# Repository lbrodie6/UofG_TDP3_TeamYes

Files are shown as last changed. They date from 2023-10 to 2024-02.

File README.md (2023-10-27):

# UofG_TDP3_TeamYes
UofG TDP3 repo for KiCAD files and code
# File Structure
- hardware: KiCad files. All PCBs can be done within the Main_Project file
    - mechanical: Mechanical CAD files. Fusion 360 .f3d, STLs and Gcode files for 3D printing are all stored here
    - photomasks: Photomasks for PCB fabrication output
- lib: Footprint libraries. Contains any custom footprints used (such as for the FRDM board).
- software: Contains C++ code

## Reference
- TCS34725 Color Sensor design files: https://github.com/adafruit/Adafruit-Flora-TCS34725-Color-Sensor-PCB/tree/master -- could be used for footprint reference
- TCS3472 mbed software library: https://os.mbed.com/users/Allar/code/TCS3472_I2C/docs/tip/classTCS3472__I2C.html
- TCS34725 datasheet: https://cdn-shop.adafruit.com/datasheets/TCS34725.pdf

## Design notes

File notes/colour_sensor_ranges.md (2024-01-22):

# Colour Sensor Ranges
C = Clear
R = Red
G = Green
B = Blue
  
### No Standoffs:
  - Red Disc: 1091C, 515R, 292G, 305B
  - Blue Disc: 992C, 243R, 328G, 419B
  - On Line: 830C, 244R, 277G, 278B
  - Off Line: 1599C, 502R, 531G, 525B

### With 6mm Standoffs:
  - Red Disc: 1140C, 557R, 270G, 284B
  - Blue Disc: 1015C, 213R, 313G, 432B
  - On Line: 712C, 199R, 228G, 234B
  - Off Line: 1781C, 540R, 578G, 575B

Tested on 19/01/24 by Izaak

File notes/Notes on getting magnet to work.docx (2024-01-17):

Setting to 12V – results in 500mA for magnet

- Logic LOW is when magnet is on – due to switch being open (should remember for programming)
- Should get a heatsink for MOSFET because it gets hawt

First:

Used just a MOSFET, and couldn’t get it working – because no pull down resistor so floating pin

- Needed at least a pull up resistor or current limiting resistor for MOSFET

Then:

Added flyback diode (1N4007) as a schottkey flyback to protect from emf spikes

Added a bjt transistor to step up 3.3V logic level from MCU to 5V – 3.3V wasn’t enough to turn on the MOSFET.

Tried different voltages to drive MOSFETs.

Higher MOSFET driving votlage means a strong magnet pull but pulls more current

MOSFET voltage | Current draw
12V | 530mA
9V | 420mA
7V | 330mA
5V | 250mA
<5V | Weak pull on magnet

Could use a voltage divider to control the current drawn – can adjust and swap these resistor values if we want to change current drawn.

- Solenoid is meant to work properly at 12V – so shall keep

http://tinyurl.com/yudysefc --- for magnet driver circuit

FET: IRF620

BJT: BC547

Diode: Schottkey (1N4007)

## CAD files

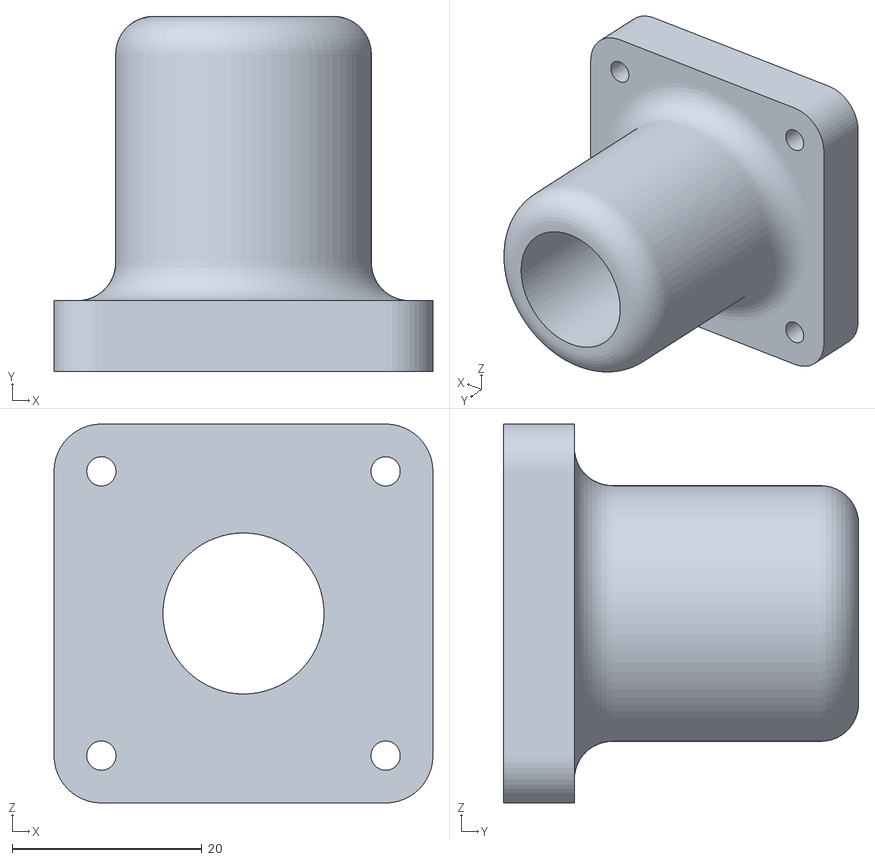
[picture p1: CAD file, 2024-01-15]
hardware/mechanical/TDP3SensorOccluder v0.stl
40.0 x 37.5 x 40.0

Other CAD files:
hardware/mechanical/GoggleOccluder.f3d
hardware/mechanical/TDP3SensorOccluder.f3d

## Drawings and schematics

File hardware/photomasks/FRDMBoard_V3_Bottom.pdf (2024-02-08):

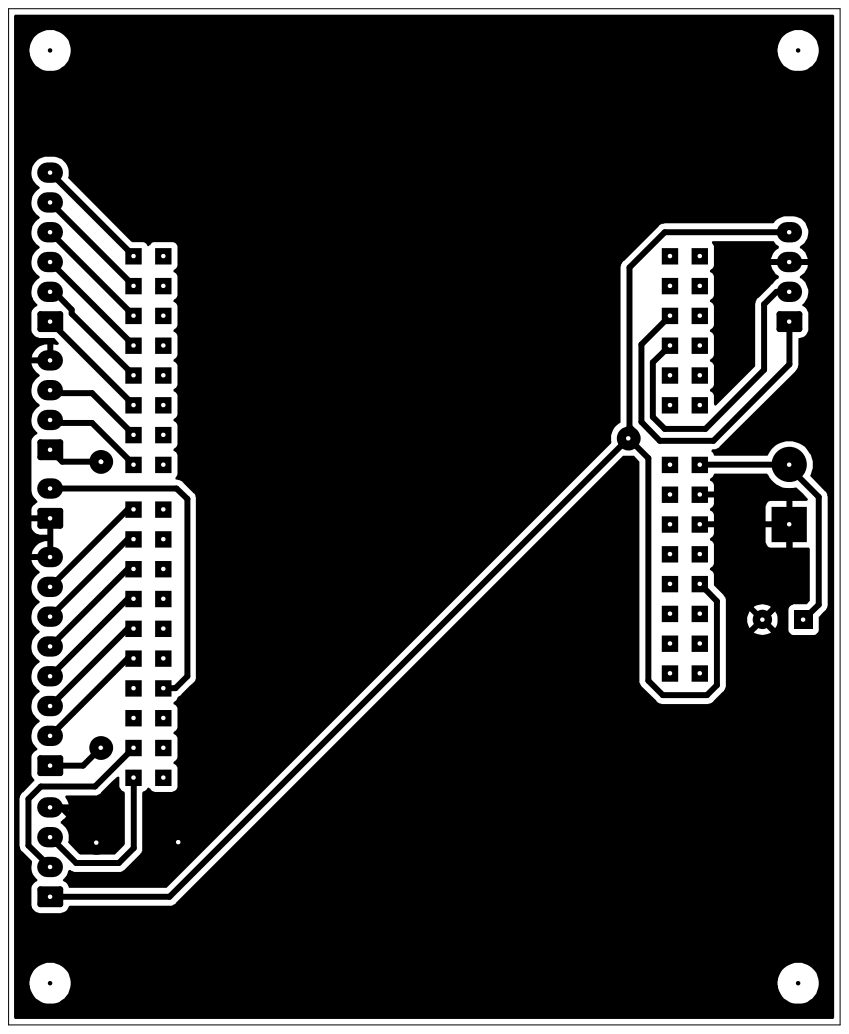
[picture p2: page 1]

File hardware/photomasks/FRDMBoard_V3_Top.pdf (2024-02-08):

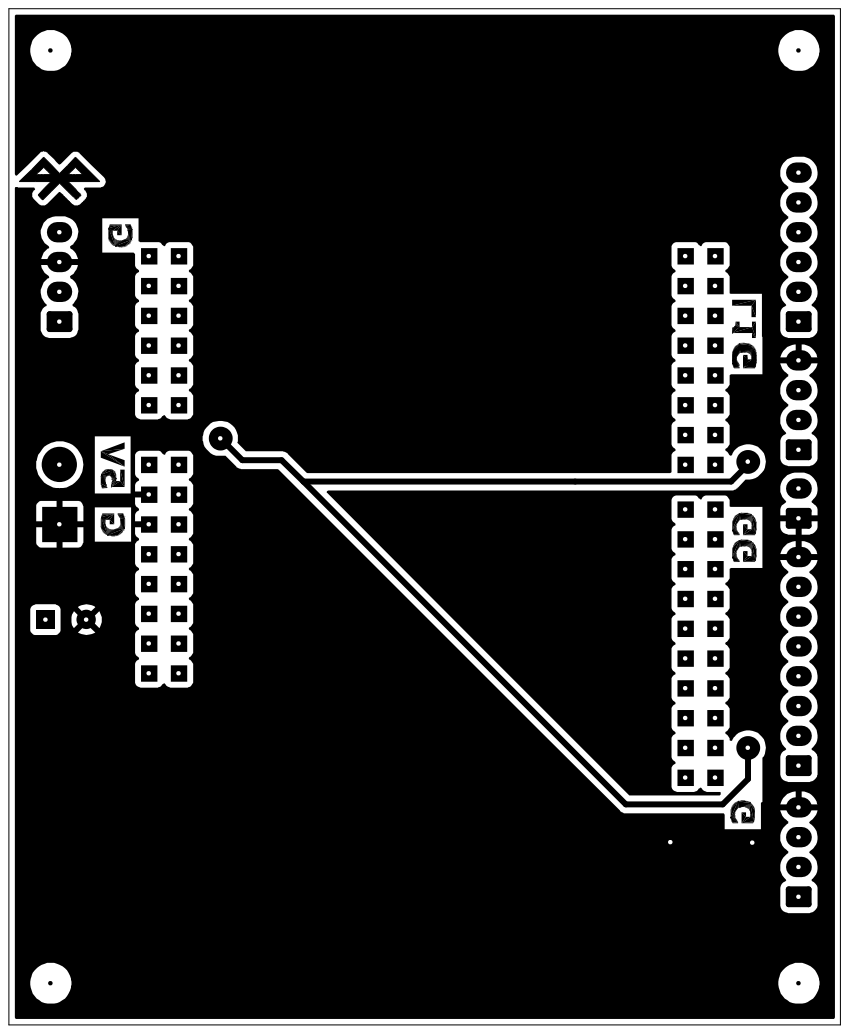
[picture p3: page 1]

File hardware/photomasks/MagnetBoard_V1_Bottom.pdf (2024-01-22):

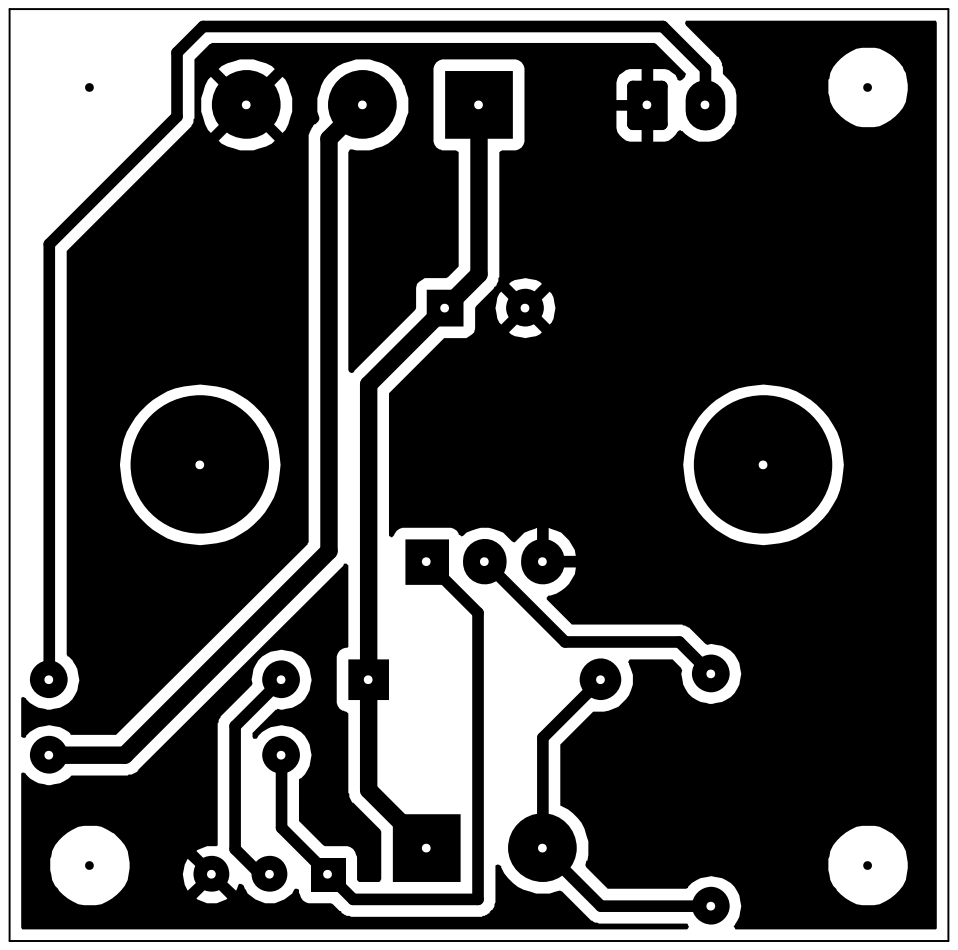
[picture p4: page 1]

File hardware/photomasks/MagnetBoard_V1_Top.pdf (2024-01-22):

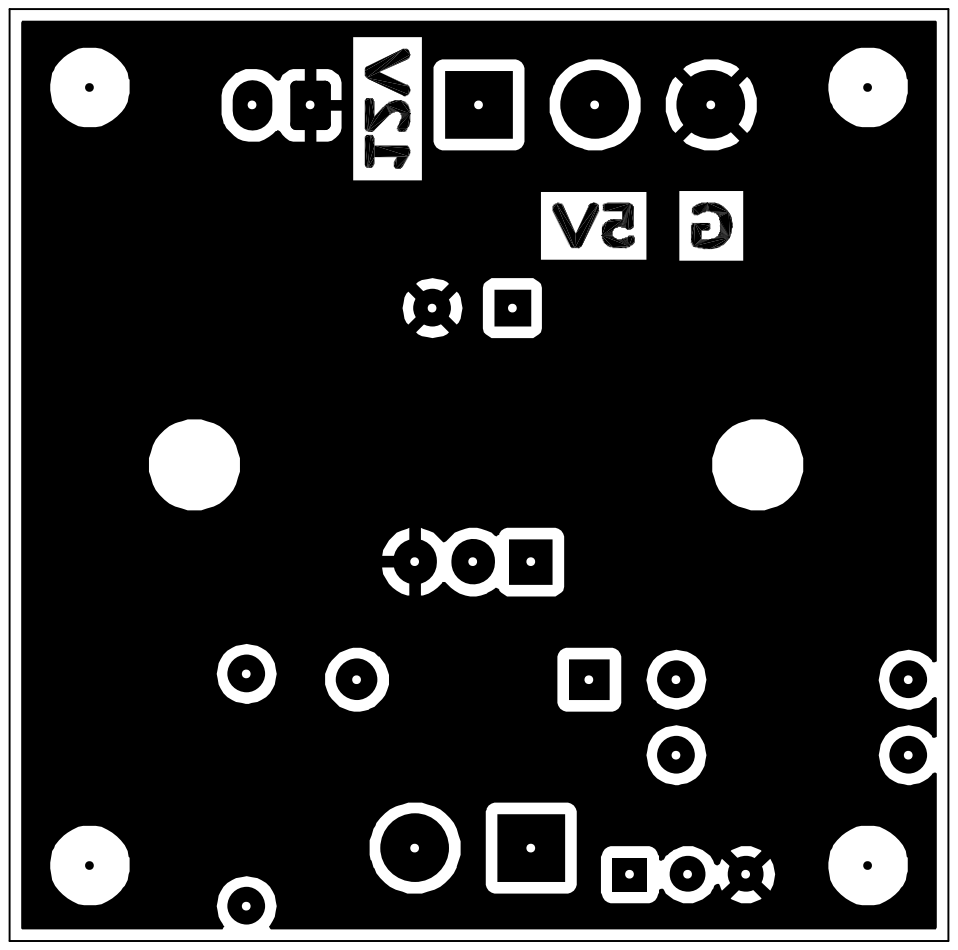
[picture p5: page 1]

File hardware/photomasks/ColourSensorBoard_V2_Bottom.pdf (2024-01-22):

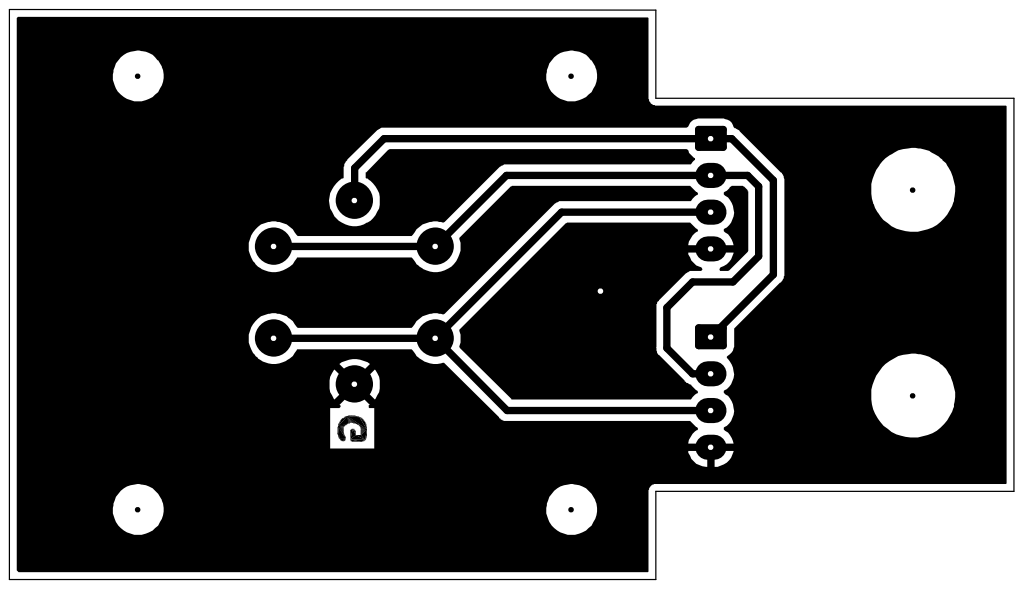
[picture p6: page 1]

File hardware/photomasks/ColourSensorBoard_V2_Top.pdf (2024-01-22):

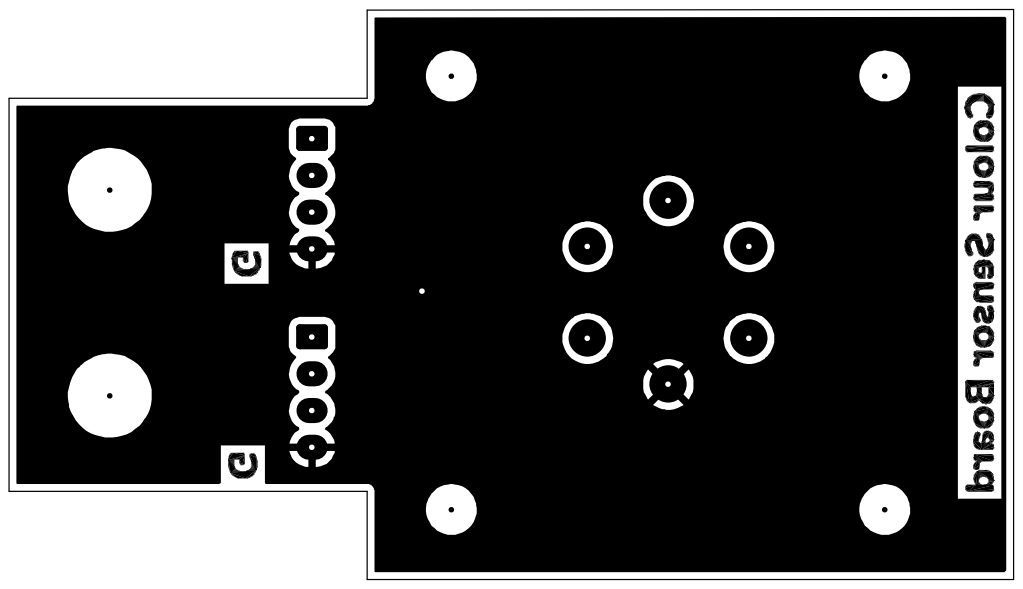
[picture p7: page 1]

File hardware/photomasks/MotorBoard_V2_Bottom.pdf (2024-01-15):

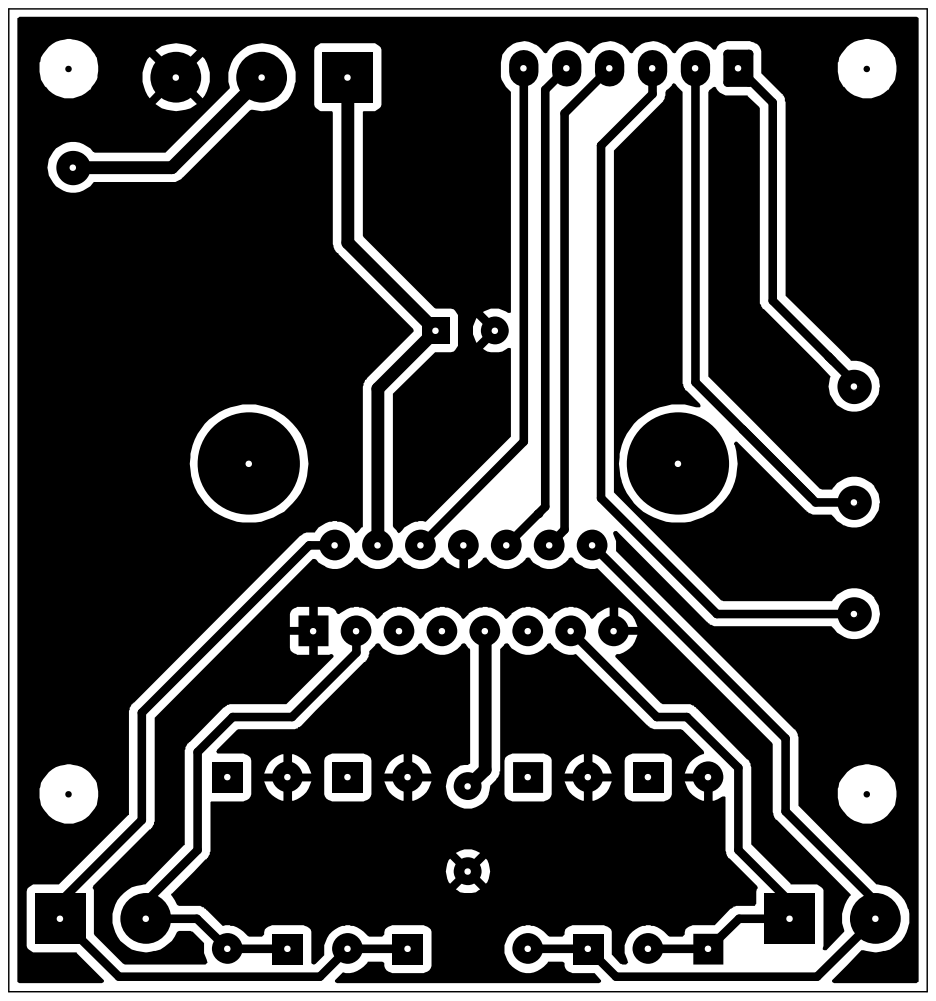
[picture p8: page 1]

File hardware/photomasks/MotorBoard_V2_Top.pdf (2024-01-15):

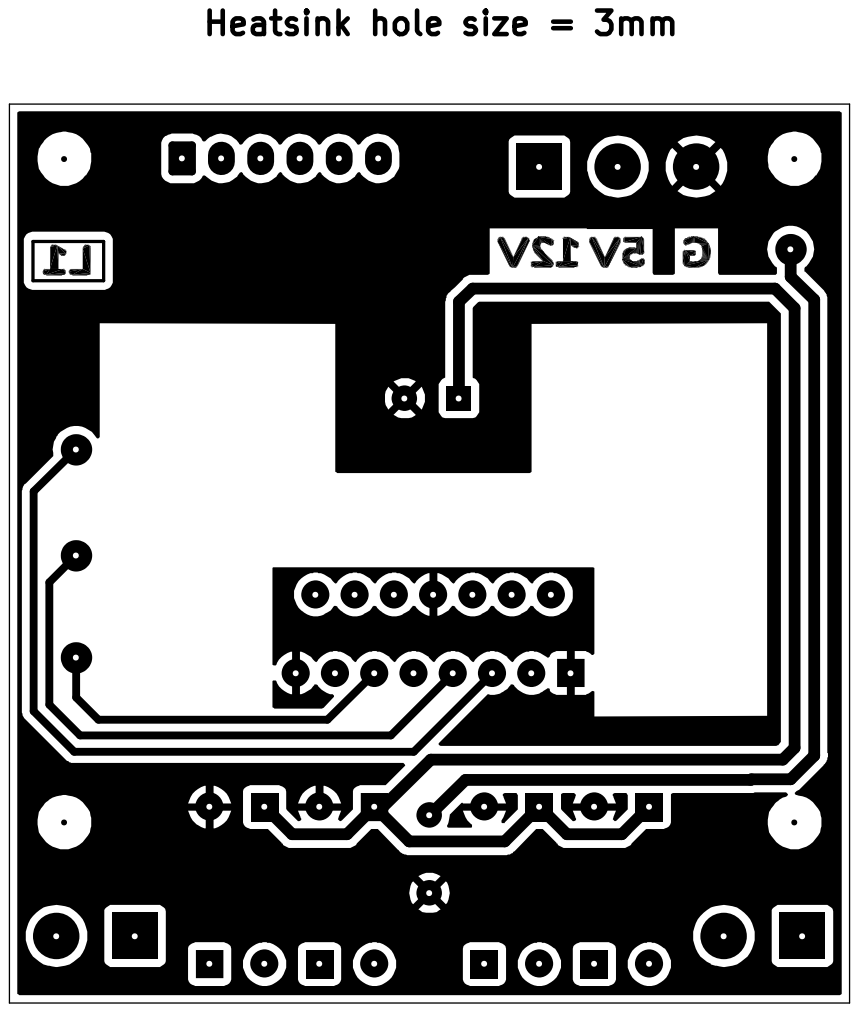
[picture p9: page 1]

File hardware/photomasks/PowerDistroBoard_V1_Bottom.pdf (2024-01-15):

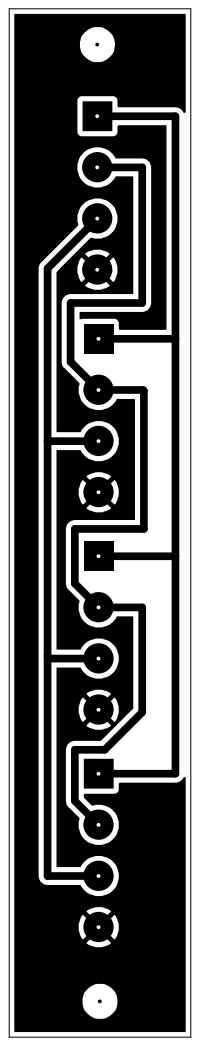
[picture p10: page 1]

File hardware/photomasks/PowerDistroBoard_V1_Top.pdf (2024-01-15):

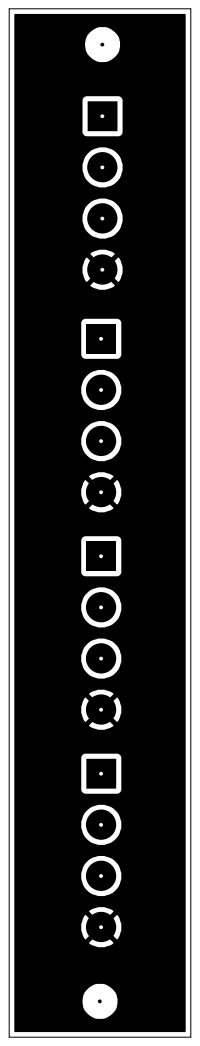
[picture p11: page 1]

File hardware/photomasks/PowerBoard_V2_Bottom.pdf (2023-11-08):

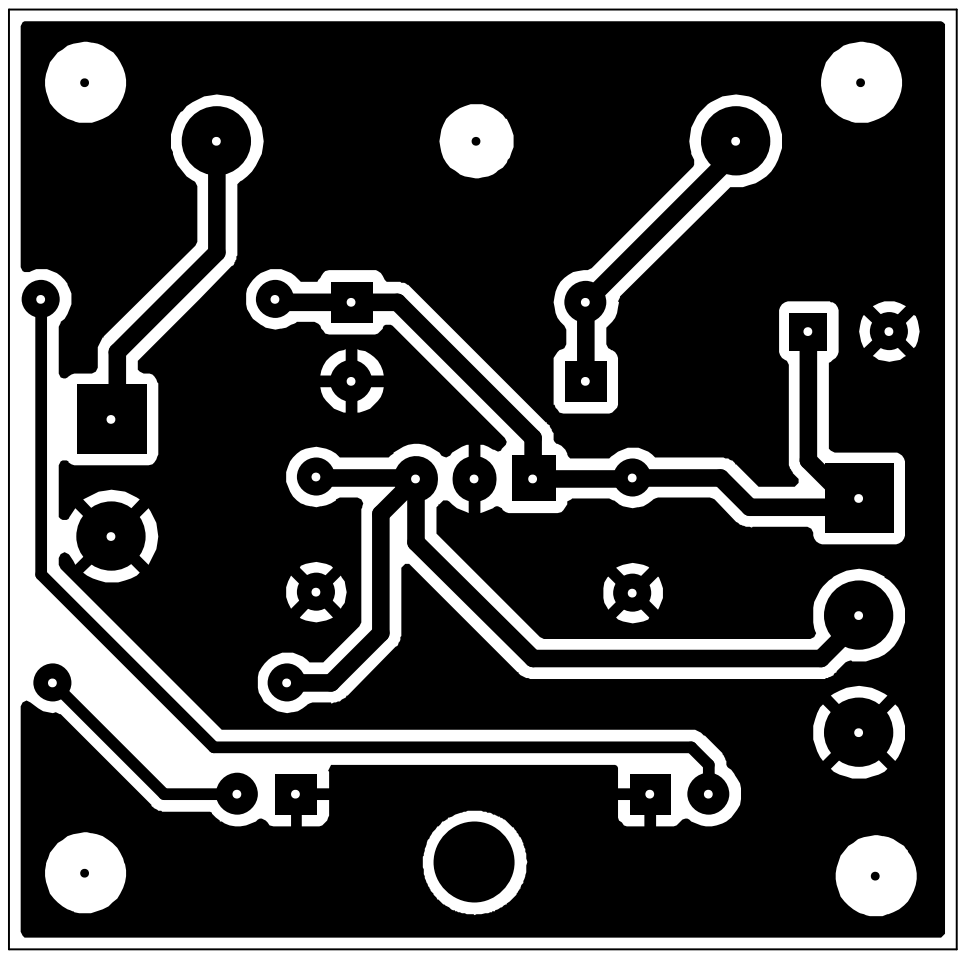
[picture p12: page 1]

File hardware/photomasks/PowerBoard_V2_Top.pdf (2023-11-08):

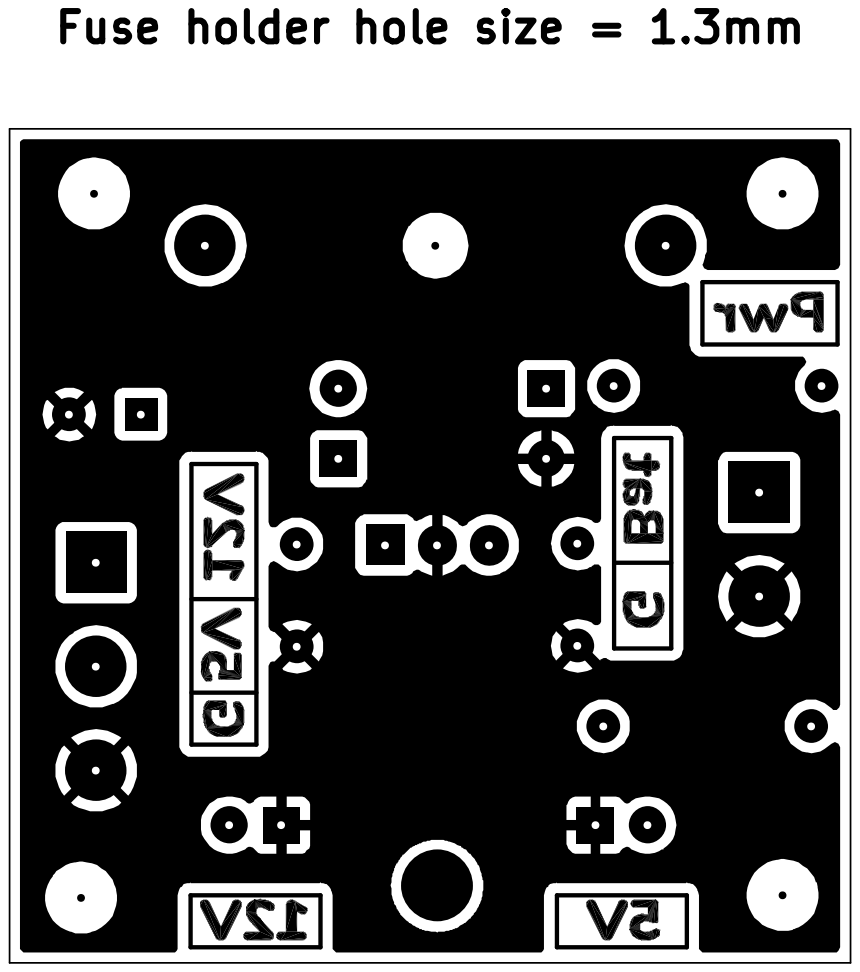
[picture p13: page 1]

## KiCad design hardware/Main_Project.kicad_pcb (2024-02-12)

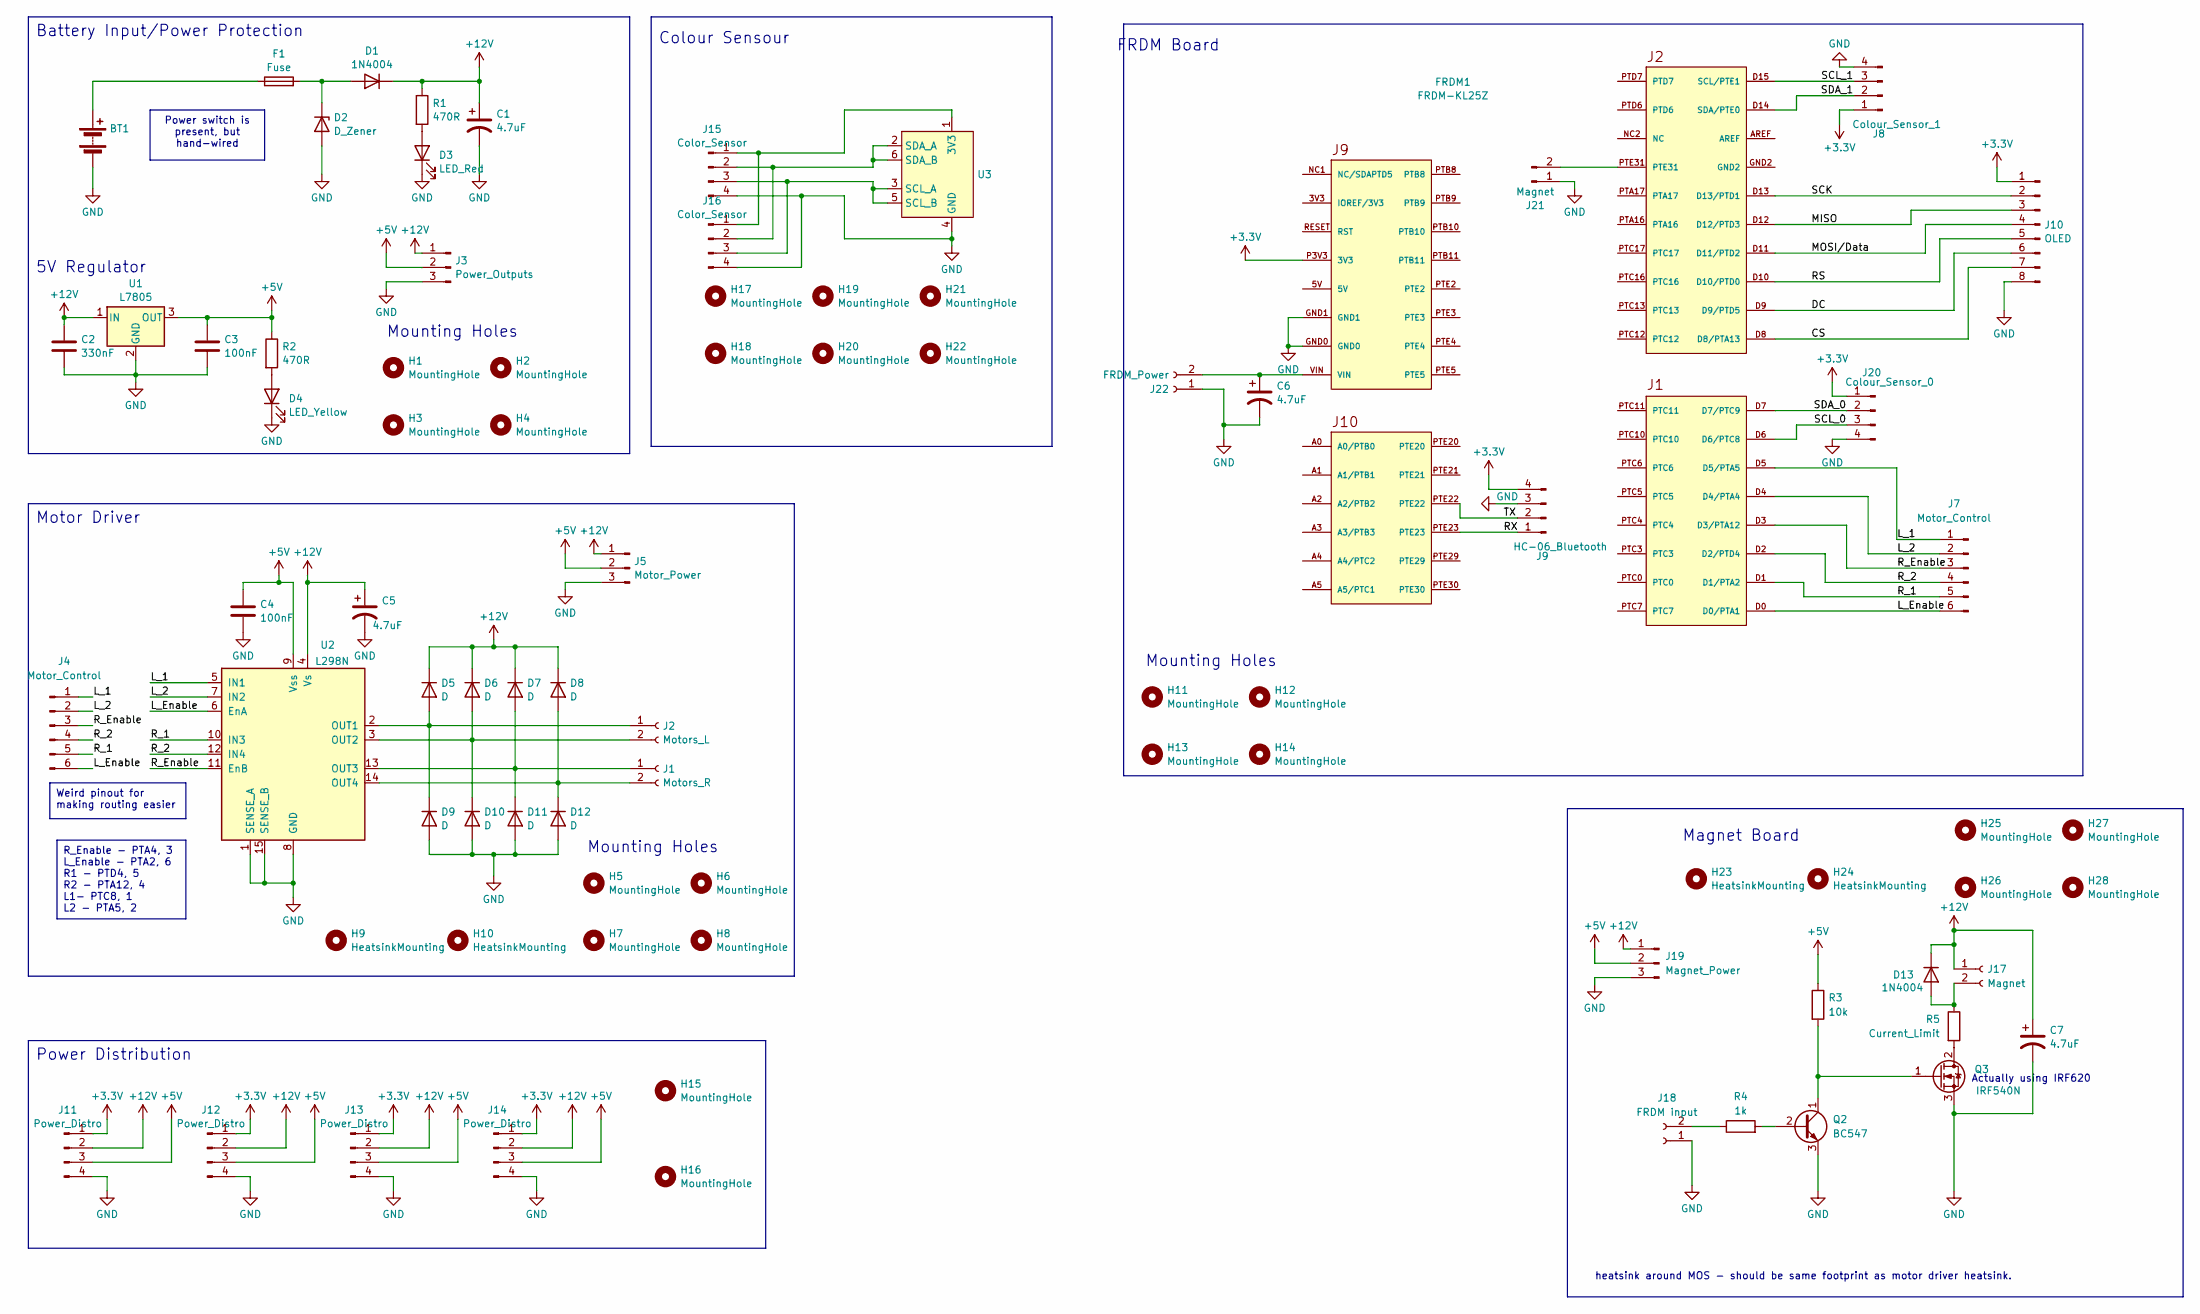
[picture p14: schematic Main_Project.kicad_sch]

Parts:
BT1: 12V Battery; TerminalBlock_bornier-2_P5.08mm
C1, C5, C6, C7: 4.7uF; CP_Radial_D8.0mm_P3.50mm
C2: 330nF; C_Disc_D8.0mm_W2.5mm_P5.00mm
C3, C4: 100nF; C_Disc_D8.0mm_W2.5mm_P5.00mm
D1, D13: 1N4004; D_A-405_P10.16mm_Horizontal
D2: D_Zener; D_A-405_P10.16mm_Horizontal
D3: LED_Red; LED_D5.0mm
D4: LED_Yellow; LED_D5.0mm
D5, D6, D7, D8, D9, D10, D11, D12: D; D_A-405_P10.16mm_Horizontal
F1: Fuse; Fuseholder_Cylinder-5x20mm_Schurter_0031_8201_Horizontal_Op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
FRDM1: FRDM-KL25Z; FRDM_KL25Z_NORMAL
H1, H2, H3, H4, H5, H6, H7, H8, H11, H12, H13, H14, H15, H16, H17, H18, H19, H20, H25, H26, H27, H28: MountingHole; MountingHole_3mm
H9, H10, H23, H24: HeatsinkMounting; M3_Heatsink_Mounting
H21, H22: MountingHole; MountingHole_5.3mm_M5
J1: Motors_R; TerminalBlock_bornier-2_P5.08mm
J2: Motors_L; TerminalBlock_bornier-2_P5.08mm
J3: Power_Outputs; TerminalBlock_bornier-3_P5.08mm
J4, J7: Motor_Control; Molex_KK-254_AE-6410-06A_1x06_P2.54mm_Vertical
J5: Motor_Power; TerminalBlock_bornier-3_P5.08mm
J8: Colour_Sensor_1; Molex_KK-254_AE-6410-04A_1x04_P2.54mm_Vertical
J9: HC-06_Bluetooth; Molex_KK-254_AE-6410-04A_1x04_P2.54mm_Vertical
J10: OLED; Molex_KK-254_AE-6410-08A_1x08_P2.54mm_Vertical
J11, J12, J13, J14: Power_Distro; TerminalBlock_bornier-4_P5.08mm
J15, J16: Color_Sensor; Molex_KK-254_AE-6410-04A_1x04_P2.54mm_Vertical
J17: Magnet; TerminalBlock_bornier-2_P5.08mm
J18: FRDM input; Molex_KK-254_AE-6410-02A_1x02_P2.54mm_Vertical
J19: Magnet_Power; TerminalBlock_bornier-3_P5.08mm
J20: Colour_Sensor_0; Molex_KK-254_AE-6410-04A_1x04_P2.54mm_Vertical
J21: Magnet; Molex_KK-254_AE-6410-02A_1x02_P2.54mm_Vertical
J22: FRDM_Power; TerminalBlock_bornier-2_P5.08mm
Q2: BC547; TO-92_Inline_Wide
Q3: IRF540N; TO-220-3_Vertical
R1, R2: 470R; R_Axial_DIN0207_L6.3mm_D2.5mm_P10.16mm_Horizontal
R3: 10k; R_Axial_DIN0207_L6.3mm_D2.5mm_P10.16mm_Horizontal
R4: 1k; R_Axial_DIN0207_L6.3mm_D2.5mm_P10.16mm_Horizontal
R5: Current_Limit; R_Axial_DIN0207_L6.3mm_D2.5mm_P10.16mm_Horizontal
U1: L7805; TO-220-3_Horizontal_TabDown
U2: L298N; TO-220-15_P2.54x2.54mm_StaggerOdd_Lead4.58mm_Vertical
U3: Adafruit_Flora_Sensor

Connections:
+3V3: FRDM1.P3V3 (3V3), J8.1, J9.4, J10.1, J11.1, J12.1, J13.1, J14.1, J20.1
+5V: C3.1, C4.1, J3.2, J5.2, J11.3, J12.3, J13.3, J14.3, J19.2, R2.1, R3.1, U1.3 (OUT), U2.9 (Vss)
+12V: C1.1, C2.1, C5.1, C7.1, D1.1 (K), D5.1 (K), D6.1 (K), D7.1 (K), D8.1 (K), D13.1 (K), J3.1, J5.1, J11.2, J12.2, J13.2, J14.2, J17.1, J19.1, R1.1, U1.1 (IN), U2.4 (Vs)
/CS: FRDM1.D8 (D8/PTA13), J10.7
/DC: FRDM1.D9 (D9/PTD5), J10.6
/L_1: FRDM1.D5 (D5/PTA5), J4.1, J7.1, U2.5 (IN1)
/L_2: FRDM1.D4 (D4/PTA4), J4.2, J7.2, U2.7 (IN2)
/L_Enable: FRDM1.D0 (D0/PTA1), J4.6, J7.6, U2.6 (EnA)
/MISO: FRDM1.D12 (D12/PTD3), J10.3
/MOSI/Data: FRDM1.D11 (D11/PTD2), J10.4
/RS: FRDM1.D10 (D10/PTD0), J10.5
/RX: FRDM1.PTE23, J9.1
/R_1: FRDM1.D1 (D1/PTA2), J4.5, J7.5, U2.10 (IN3)
/R_2: FRDM1.D2 (D2/PTD4), J4.4, J7.4, U2.12 (IN4)
/R_Enable: FRDM1.D3 (D3/PTA12), J4.3, J7.3, U2.11 (EnB)
/SCK: FRDM1.D13 (D13/PTD1), J10.2
/SCL_0: FRDM1.D6 (D6/PTC8), J20.3
/SCL_1: FRDM1.D15 (SCL/PTE1), J8.3
/SDA_0: FRDM1.D7 (D7/PTC9), J20.2
/SDA_1: FRDM1.D14 (SDA/PTE0), J8.2
/TX: FRDM1.PTE22, J9.2
GND: BT1.2 (-), C1.2, C2.2, C3.2, C4.2, C5.2, C6.2, C7.2, D2.2 (A), D3.1 (K), D4.1 (K), D9.2 (A), D10.2 (A), D11.2 (A), D12.2 (A), FRDM1.GND0, FRDM1.GND1, J3.3, J5.3, J8.4, J9.3, J10.8, J11.4, J12.4, J13.4, J14.4, J15.4, J16.4, J18.1, J19.3, J20.4, J21.1, J22.1, Q2.3 (E), Q3.3 (S), U1.2 (GND), U2.1 (SENSE_A), U2.8 (GND), U2.15 (SENSE_B), U3.4 (GND)
unnamed: BT1.1 (+), F1.1
unnamed: D1.2 (A), D2.1 (K), F1.2
unnamed: D3.2 (A), R1.2
unnamed: D4.2 (A), R2.2
unnamed: D5.2 (A), D9.1 (K), J2.1, U2.2 (OUT1)
unnamed: D6.2 (A), D10.1 (K), J2.2, U2.3 (OUT2)
unnamed: D7.2 (A), D11.1 (K), J1.1, U2.13 (OUT3)
unnamed: D8.2 (A), D12.1 (K), J1.2, U2.14 (OUT4)
unnamed: D13.2 (A), J17.2, R5.1
unnamed: J15.1, J16.1, U3.1 (3V3)
unnamed: J15.2, J16.2, U3.2 (SDA_A), U3.6 (SDA_B)
unnamed: J15.3, J16.3, U3.3 (SCL_A), U3.5 (SCL_B)
unnamed: J18.2, R4.1
unnamed: FRDM1.PTE31, J21.2
unnamed: C6.1, FRDM1.VIN, J22.2
unnamed: Q2.2 (B), R4.2
unnamed: Q2.1 (C), Q3.1 (G), R3.2
unnamed: Q3.2 (D), R5.2

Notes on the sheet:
Power switch is present, but hand-wired
Weird pinout for making routing easier
R_Enable - PTA4, 3 L_Enable - PTA2, 6 R1 - PTD4, 5 R2 - PTA12, 4 L1- PTC8, 1 L2 - PTA5, 2
Mounting Holes
Power Distribution
heatsink around MOS - should be same footprint as motor driver heatsink.
5V Regulator
Actually using IRF620
Battery Input/Power Protection
Colour Sensour
FRDM Board
Magnet Board
Motor Driver

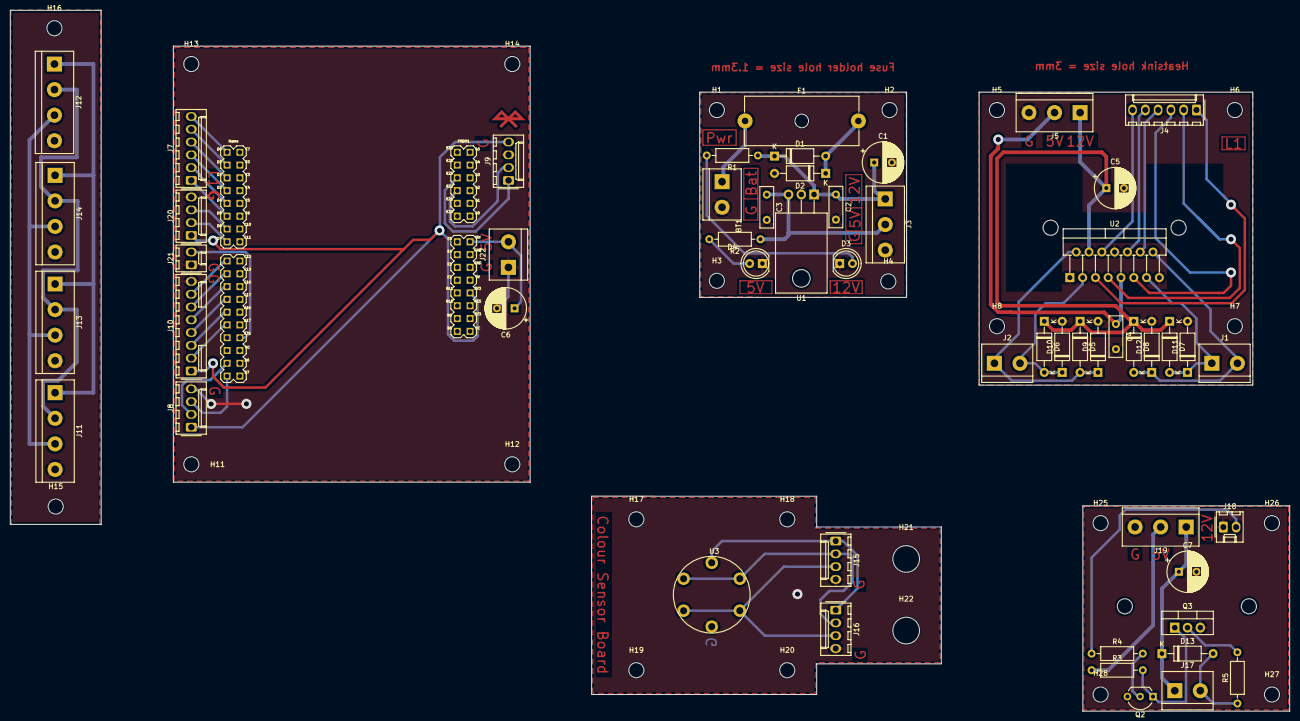
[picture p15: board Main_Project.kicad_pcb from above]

Board: 2 copper layers, 254.1 x 139.2 mm, 82 parts (0 on the bottom side), 40 nets.

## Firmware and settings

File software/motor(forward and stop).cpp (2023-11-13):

#include "mbed.h"


// Define L298N motor control pins
PwmOut PwmR(PTA4);//control right 
DigitalOut Rforward(PTC3);  // Adjust these pin assignments as per your connection
DigitalOut Rbackward(PTC4);

PwmOut PwmL(PTA5);//control left
DigitalOut Lforward(PTC5);
DigitalOut Lbackward(PTC6);

void control_R(float dutycycle, bool direction) {
    PwmR = dutycycle;
    if (direction==1){
    Rforward = 1;
    Rbackward = 0;
    }
    else{
    Rforward = 0;
    Rbackward = 1;
    }
}

void stopMotor() {
    Rforward = 0;
    Rbackward = 0;
    Lforward = 0;
    Lbackward = 0;

}

void control_L(float dutycycle, bool direction) {
    PwmL = dutycycle;
    if(direction==1){
    Lforward = 1;
    Lbackward = 0;
    }
    else{
    Lforward = 0;
    Lbackward = 1;
    }
}



int main() {
    while(1){
        for (float i = 0.0; i < 500; i++){ 
            control_R(i/500.0,1);
            control_L(i/500.0,1);
            wait_us(40000);
        }
        stopMotor();
        wait_us(5000000);//start speed 0.5

        control_R(0.1,1);
        control_L(0.1,1);
        wait_us(5000000);//start speed 0.5

        stopMotor();
        wait_us(5000000);//start speed 0.5

        control_R(1,1);
        control_L(1,1);
        wait_us(5000000);//start speed 0.5

        stopMotor();
         wait_us(1000000);//start speed 0.5

        control_R(0.1,0);
        control_L(0.1,0);
        wait_us(5000000);//start speed 0.5

        stopMotor();
        wait_us(1000000);//start speed 0.5

        control_R(1,0);
        control_L(1,0);
        wait_us(5000000);//start speed 0.5

        stopMotor();
        wait_us(1000000);//start speed 0.5 

        control_R(0.5,1);
        control_L(1,1);
        wait_us(5000000);//start speed 0.5

        stopMotor();
        wait_us(1000000);//start speed 0.5

        control_R(1,1);
        control_L(0.5,1);
        wait_us(5000000);//start speed 0.5  

        stopMotor();
    }


}
        if (rgb_readings[3] > rgb_readings[1] && rgb_readings[3] > rgb_readings[2]) {
            printf("Blue is highest\n");
        }
        wait_us(100000);
    }
}

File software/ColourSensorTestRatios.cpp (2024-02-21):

#include "mbed.h"
#include "TCS3472_I2C.h"
// https://os.mbed.com/users/Allar/code/TCS3472_I2C/
// ensure library has char cast to char fixed

// Pin initialisation
TCS3472_I2C rgb_sensor_L(PTE0, PTE1);
TCS3472_I2C rgb_sensor_R(PTC9, PTC8);
DigitalOut boardled(LED1);
DigitalOut Electromagnet(PTE31,PullUp);
// DigitalOut green(PTA4);
// DigitalOut blue(PTA12);
// DigitalOut lineLED(PTA13);
//AnalogOut led(PTE30);
// AnalogIn line_threshold(PTB0);

void sensorsInitialise(int int_time) {
    rgb_sensor_R.enablePowerAndRGBC();
    rgb_sensor_L.enablePowerAndRGBC();
    rgb_sensor_R.setIntegrationTime(int_time);
    rgb_sensor_L.setIntegrationTime(int_time);
}

double getLineConstant(int clear_R, int clear_L) {
        int denominator = ((clear_L) + (clear_R));
        int numerator = (clear_L);
        float ratio = static_cast<float>(numerator) / denominator;
        int percent = static_cast<int>(ratio*100);
        return ratio;
}

// void sensorsGetRatios(int rgb_readings_R[4], int rgb_readings_L[4])/{
//     rgb_sensor_R.getAllColors(rgb_readings_R);
//     rgb_sensor_L.getAllColors(rgb_readings_L);
//     printf("RIGHT: clear: %d, red: %d, green: %d, blue: %d\n", rgb_readings_R[0],rgb_readings_R[1], rgb_readings_R[2], rgb_readings_R[3]);
//     printf("LEFT: clear: %d, red: %d, green: %d, blue: %d\n", rgb_readings_L[0],rgb_readings_L[1], rgb_readings_L[2], rgb_readings_L[3]);
// // Ratios of colours divided by other two colour values values
//     // Right Sensor
//     red_ratio_R = rgb_readings_R[1] / ((rgb_readings_R[2] + rgb_readings_R[3]));
//     green_ratio_R = rgb_readings_R[2] / ((rgb_readings_R[1] + rgb_readings_R[3]));
//     blue_ratio_R = rgb_readings_R[3] / ((rgb_readings_R[1] + rgb_readings_R[2]));
//     // Left Sensor
//     red_ratio_L = rgb_readings_L[1] / ((rgb_readings_L[2] + rgb_readings_L[3]));
//     green_ratio_L = rgb_readings_L[2] / ((rgb_readings_L[1] + rgb_readings_L[3]));
//     blue_ratio_L = rgb_readings_L[3] / ((rgb_readings_L[1] + rgb_readings_L[2]));
//     return(red_ratio_R, green_ratio_R, blue_ratio_R, red_ratio_L, green_ratio_L, blue_ratio_L, rgb_readings_R, rgb_readings_L)
// }

// Main program
int main() {

// Variable initiation
    float threshold[4] = {1250.0, 3.0, 3.0, 2.5};
    int rgb_readings_R[4];
    int rgb_readings_L[4];
    double line_constant;
    // Right Sensor
    float red_ratio_R;
    float green_ratio_R;
    float blue_ratio_R;
    // Left Sensor
    float red_ratio_L;
    float green_ratio_L;
    float blue_ratio_L;
// Initialising the sensor values - sent through I2C to sensor peripheral. Integration time sent as an argument to the function
    sensorsInitialise(20);

// Main program loop
    while (1) {
    
    // Collect RGB readings from sensors
        rgb_sensor_R.getAllColors(rgb_readings_R);
        rgb_sensor_L.getAllColors(rgb_readings_L);
        line_constant = getLineConstant(rgb_readings_R[0],rgb_readings_L[0]);
        int percent = static_cast<int>(line_constant*100);
        printf("Line constant percent --- \nPercent (LC*100): %d \n", percent);
    // Prints RGB readings to output, e.g. Putty. (For bug testing/troubleshooting)    
        //printf("RIGHT: clear: %d, red: %d, green: %d, blue: %d\n", rgb_readings_R[0],rgb_readings_R[1], rgb_readings_R[2], rgb_readings_R[3]);
        //printf("LEFT: clear: %d, red: %d, green: %d, blue: %d\n", rgb_readings_L[0],rgb_readings_L[1], rgb_readings_L[2], rgb_readings_L[3]);
    
    // Ratios of colours divided by other two colour values values
        // Right Sensor
        
        red_ratio_R = rgb_readings_R[1] / ((rgb_readings_R[2] + rgb_readings_R[3]));
        green_ratio_R = rgb_readings_R[2] / ((rgb_readings_R[1] + rgb_readings_R[3]));
        blue_ratio_R = rgb_readings_R[3] / ((rgb_readings_R[1] + rgb_readings_R[2]));
        // Left Sensor
        red_ratio_L = rgb_readings_L[1] / ((rgb_readings_L[2] + rgb_readings_L[3]));
        green_ratio_L = rgb_readings_L[2] / ((rgb_readings_L[1] + rgb_readings_L[3]));
        blue_ratio_L = rgb_readings_L[3] / ((rgb_readings_L[1] + rgb_readings_L[2]));

    // Setting logic statements to 0
        // EM Disk
        bool blue_pickup;
        bool red_pickup;
        // Right Sensor
        bool red_R = false;
        bool green_R = false;
        bool blue_R = false;
        // Left Sensor
        bool red_L = false;
        bool green_L = false;
        bool blue_L = false;

    // Decision function for Red, Green, and Blue detection (respectively)
        // Right Sensor
        if (red_ratio_R > threshold[1]) {
        // printf("Red is highest\n");
        red_R = true;
        }
        if (green_ratio_R > threshold[2]) {
        // printf("Green is highest\n");
        green_R = true;
        }
        if (blue_ratio_R > threshold[3]) {
        // printf("Blue is highest\n");
        blue_R = true;
        }

        // Left Sensor
        if (red_ratio_L > threshold[1]) {
        // printf("Red is highest\n");
        red_L = true;
        }
        if (green_ratio_L > threshold[2]) {
        // printf("Green is highest\n");
        green_L = true;
        }
        if (blue_ratio_L > threshold[3]) {
        // printf("Blue is highest\n");
        blue_L = true;
        }

    
        wait_us(400000); // Replace with PID controller and move wait to after - wait must be >20000us to allow for integration time
        // // Red Disk flags for pickup and drop off
        // if (red_R == true && red_L == false) {
        // // Electromagnet Trigger ON
        // red_pickup = true;
        // } else if (red_R == true && red_L == true && red_pickup == true) {
        // // Electromagnet Trigger OFF
        // red_pickup = false;
        // }
        // else{
        //         wait_us(1);
        // }

        // // Blue Disk flags for pickup and drop off
        // if (blue_R == true && blue_L == false) {
        // // Electromagnet Trigger ON
        // Electromagnet = 0;
        // } else if (blue_R == true && blue_L == true && blue_pickup == true) {
        // // Electromagnet Trigger OFF
        // blue_pickup = false;
        // }
        // else{
        //     wait_us(1);      
        // }
    }
}

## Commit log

2023-10-13 Added Hardware Files
    [Main_Project.kicad_pcb, Main_Project.kicad_sch]
2023-10-13 kicad backups
2023-10-13 Added example text
    [Main_Project.kicad_sch]
2023-10-19 Added footprints for Colour sensor and reorganized libraries
    [Main_Project.kicad_pcb, Main_Project.kicad_sch]
2023-10-23 Changed PCB slightly
    [Main_Project.kicad_pcb, Main_Project.kicad_sch]
2023-10-24 Added colour sensor test code
2023-10-24 Added 'mechanical' for any 3D-printed parts
    [TDP3SensorOccluder.f3d]
2023-10-25 Added dual occluder for line sensing
    [GoggleOccluder.f3d]
2023-10-25 Colour Sensor Code updated for demo
2023-10-26 Renamed AnalogIn pin
2023-10-26 Create motor(forward and stop)
2023-10-27 Minor changes
    [Main_Project.kicad_pcb]
2023-10-27 Moved Peter's Motor code
2023-10-27 Created Power PCB
    [Main_Project.kicad_pcb]
2023-10-27 Created photomasks folder and made photomasks for power PCB
    [Main_Project.kicad_pcb]
2023-10-29 Motor Control Code V2
    ZIP file, keil studio
2023-11-01 changed resistor values
    [Main_Project.kicad_sch]
2023-11-08 Motor Board
    [Main_Project.kicad_pcb, Main_Project.kicad_sch]
2023-11-08 Revert "Merge branch 'main' of https://github.com/Izaakthegreat/UofG_TDP3_TeamYes"
    This reverts commit c94bb09d7ba82349e4f842fc72250d60d35b9314, reversing
    changes made to e7193e99aa60d7a7ac14a2fac5b26370316d7b60.
    [Main_Project.kicad_sch]
2024-01-11 notes for magnet circuit
2024-01-15 Colour Sensor board added and adjusted
    [Main_Project.kicad_pcb, Main_Project.kicad_sch, TDP3SensorOccluder v0.stl]
2024-01-17 added notes for priority of tasks
    xxx
    [Main_Project.kicad_sch]
2024-01-17 Updated Colour Sensor Board to fit properly
    [Main_Project.kicad_pcb]
2024-01-21 Colour Sensor Testing with Line Detection updated
    Still need to figure out how data from both sensors will come into the microcontroller
2024-01-22 new pcb for magnet
    [Main_Project.kicad_pcb, Main_Project.kicad_sch]
2024-01-22 Magnet board
    [Main_Project.kicad_pcb, Main_Project.kicad_sch]
2024-01-31 New FRDM Board
    [Main_Project.kicad_pcb, Main_Project.kicad_sch]
2024-02-02 Updated PCB with connections all B-side, and unrouted track fixed
    [Main_Project.kicad_pcb]
2024-02-02 PCB updated again, one more issue fixed
2024-02-08 Updated FRDM pcb and photomasks
    [Main_Project.kicad_pcb, Main_Project.kicad_sch]
2024-02-08 Updated Sensor code
2024-02-12 kicad autosave bs
    [Main_Project.kicad_pcb]
2024-02-21 No real changes just weird bits and bobs from opening the kicad I think
